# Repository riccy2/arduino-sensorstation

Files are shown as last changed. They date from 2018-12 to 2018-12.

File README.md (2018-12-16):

# Arduino Sensorstation

## Zusammenfassung
Hochpräzise Vermessungsarbeiten erfordern oft eine genaue Kenntnis des Mediums Luft. Temperatur, Luftdruck und relative Luftfeuchte beeinflussen die benötige Laufzeit von Wellen, die für Streckenmessungen genutzt werden. Das Ziel dieser Arbeit ist, eine kostengünstige Lösung zu entwickeln, die es ermöglicht, flächendeckend Korrekturwerte für hochpräzise Messungen zu liefern. Dazu wird mithilfe der Hard- und Softwareplattform Arduino ein Prototyp entwickelt, welcher Temperatur, Luftdruck und Luftfeuchte messen und an eine zentrale Stelle via WLAN weiterleiten kann. Dazu wurden verschiedene Sensoren hinsichtlich ihrer Genauigkeit untersucht und weitere für eine ausfallsichere Datenerfassung benötigte Komponenten ausgewählt. Ein Programm für die Steuerung einer Messstation sowie für den zentralen Server wurde entwickelt. Das Ergebnis ist Sensornetzwerk, dessen Knoten einen Materialpreis von etwas über 10 € aufweisen und trotzdem genaue Messwerte erfassen.

## Abstract
High-precision surveying work often requires precise knowledge of the medium air. Temperature, air pressure and relative humidity influence the required running time of waves used for distance measurements. The aim of this work is to develop a cost-effective solution that allows to provide area-wide correction values for high-precision measurements. A prototype will be developed using the Arduino hardware and software platform, which can measure temperature, air pressure and humidity and transmit them to a central location via WLAN. For this purpose, various sensors were examined with regard to their accuracy and further components required for fail-safe data acquisition were selected. A program to control a sensor station as well as one for the central server was developed. The result is a sensor network, whose nodes have a material price of just over 10 € and still record accurate measured values.

## Inhalt dieses Repository

### Bachelor Thesis
Die pdf-Datei **thesis.pdf** enthält die Bachelor-Thesis **Low-cost Umweltmonitoring mit Arduino in Geosensornetzwerken** von Riccardo Oppermann. Betreut wurde diese Arbeit an der HafenCity Universität Hamburg von den Herren Prof. Dr.-Ing. Harald Sternberg und Dipl.-Umweltwiss. Dipl.-Ing. Günter Eppinger.

### Arduino Code
Dieser Ordner enthält den Quellcode für eine Sensorstation. **SensorStation.ino** ist das Main Sketch File.

### Layout
Dieser Ordner enthält ein Bild des mit fritzing erstellten Layouts sowie Schaltplans einer Sensorstaton. Ebenfalls finden sich dort Bilder einer fertigen Sensorstation auf einem PCB.

### PCB-Design
In diesem Ordner ist das entworfene Board in Form einer Eagle-CAD-Boarddatei sowie einer fertigen Gerber-Datei.

### Server-Code
In diesem Ordner befindet sich der Code des PHP-Scripts zum Speichern der Messwerte (**send_data.php**) sowie eines zum Abrufen von Daten (**get_data.php**). Dieses Script zum Abrufen wird von der Testapplikation **index.php** genutzt. Die Testaplikation kann die Daten verschiedener Stationen in einer mit AmCharts erstellten Grafik darstellen.
Die Datei **weather.sql** enthält die Struktur der MySQL-Datenbank.

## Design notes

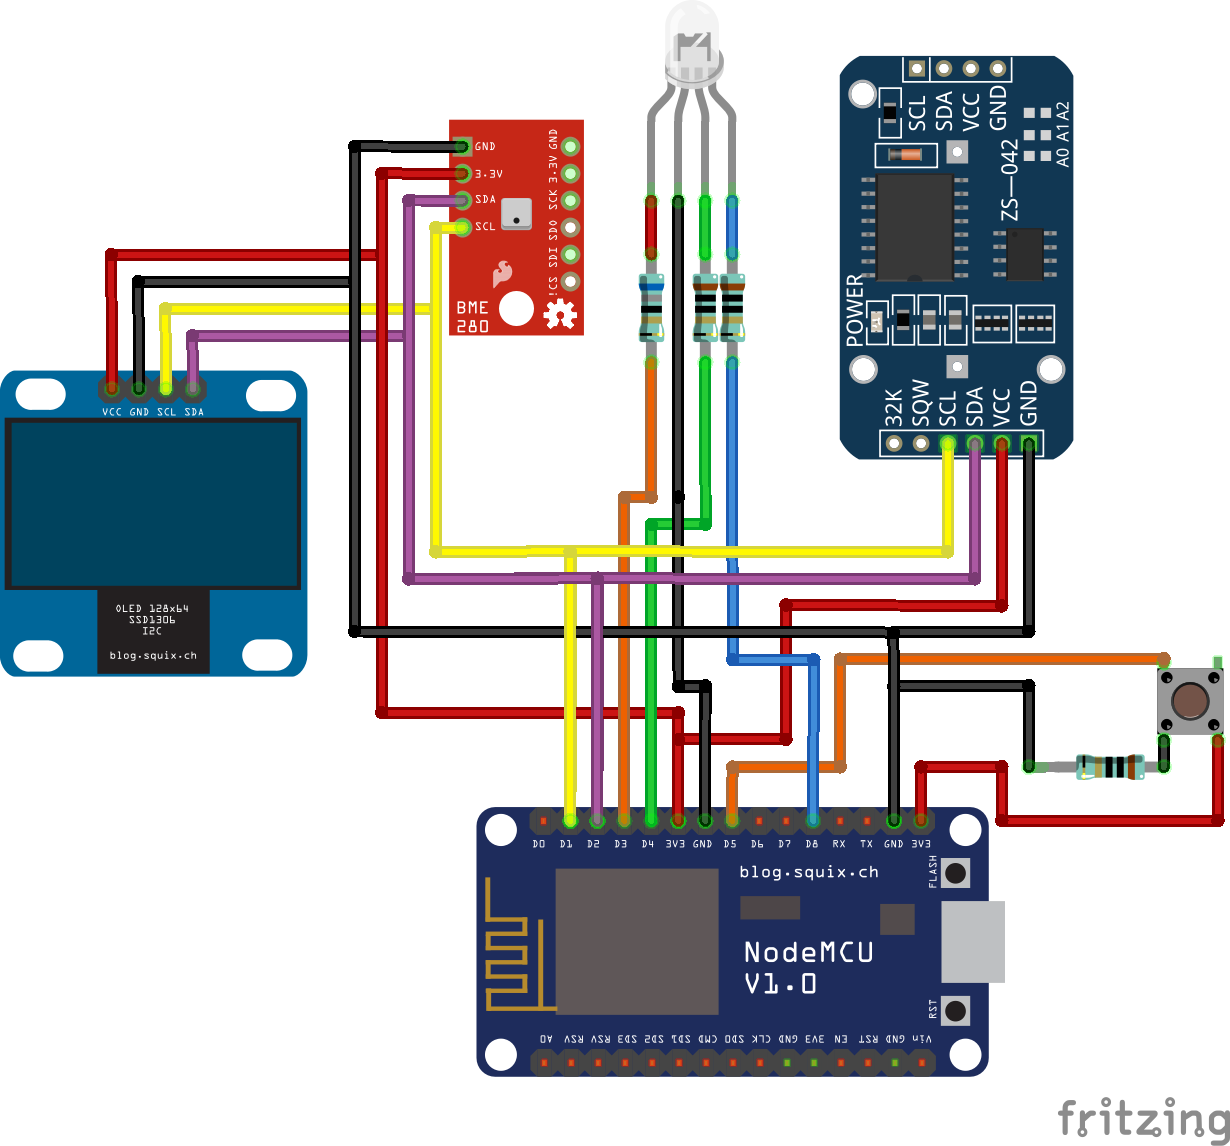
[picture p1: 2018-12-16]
Layout/layout_Steckplatine.png

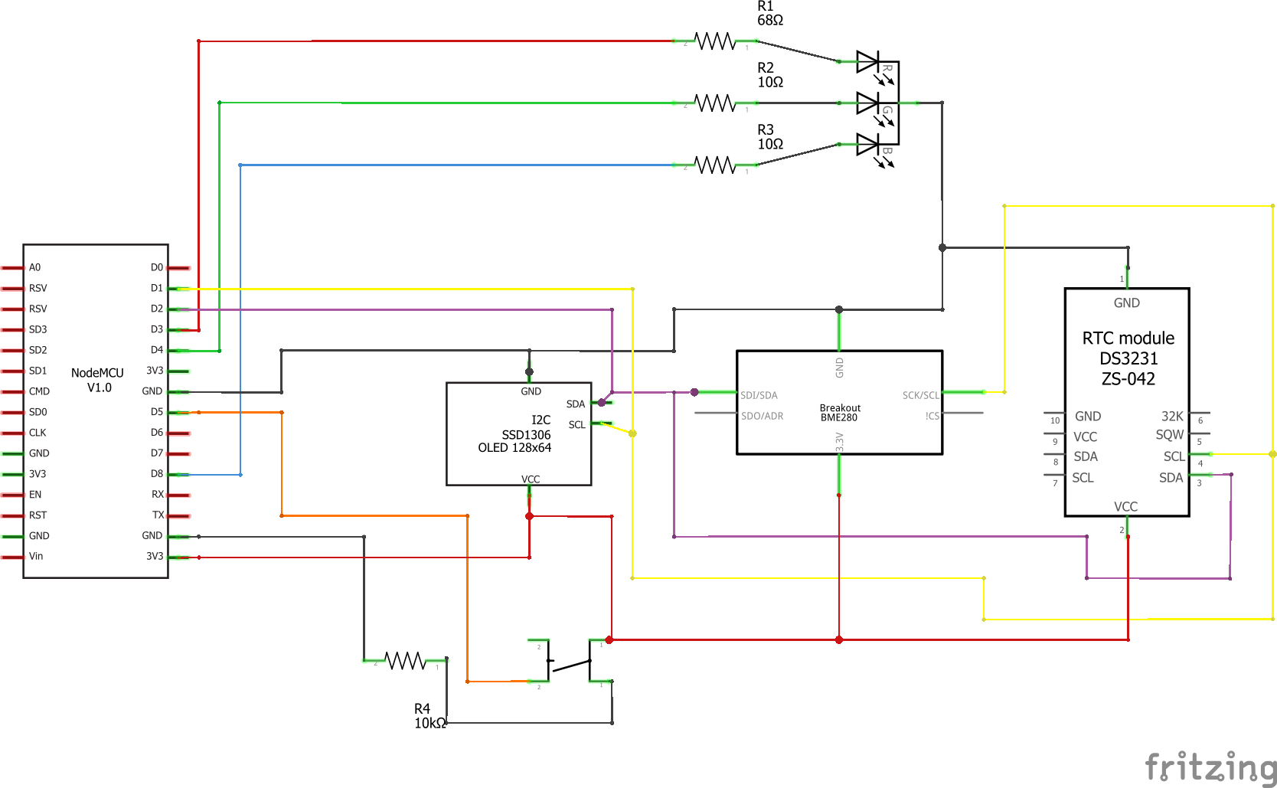
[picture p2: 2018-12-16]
Layout/layout_Schaltplan.png

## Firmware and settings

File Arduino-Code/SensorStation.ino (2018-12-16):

/*
   ** SensorStation **
   Programm zur Erfassung und Übermittlung von Wetterdaten
   Autor: Riccardo Oppermann
   Datum: November + Dezember 2018
   Verwendete Komponenten: NodeMCU v2 Amica, Bosch BME280 Modul, DS3231 RTC Modul, 1.3" I2C OLED Display, 

   NodeMCU I2C
   SDA -> D2 (GPIO 4) Standard
   SCL -> D1 (GPIO 5) Standard
   Falls andere Pins genutzt werden sollen, diese festlegen mit Wire.begin(SDApin,SCLpin);

   LED
   Rot  -> D3 (GPIO 0)
   Grün -> D4 (GPIO 2)
   Blau -> D8 (GPIO 15)

   Button
   Signal -> D5 (GPIO 14)
   

*/

#include <FS.h>                   //muss an erster Stelle stehen

#include <Adafruit_Sensor.h>      //https://github.com/adafruit/Adafruit_Sensor
#include <Adafruit_BME280.h>      //https://github.com/adafruit/Adafruit_BME280_Library change I2C-Adress to 0x76
#include <RTClib.h>               //https://github.com/adafruit/RTClib
#include <U8g2lib.h>              //https://github.com/olikraus/u8g2
#include <U8x8lib.h>              //https://github.com/olikraus/u8g2
#include <Wire.h>                 //https://www.arduino.cc/en/Reference/Wire
#include <SPI.h>                  //https://www.arduino.cc/en/Reference/SPI
#include <ESP8266WiFi.h>          //https://github.com/esp8266/Arduino
#include <DNSServer.h>            //https://github.com/esp8266/Arduino
#include <ESP8266WebServer.h>     //https://github.com/esp8266/Arduino
#include <WiFiClientSecure.h>     //https://github.com/esp8266/Arduino
#include <WiFiManager.h>          //https://github.com/tzapu/WiFiManager
#include <ArduinoJson.h>          //https://github.com/bblanchon/ArduinoJson Version 5.X.X


WiFiClientSecure client;
WiFiManager wifiManager;
File logDatei;
String line;
Adafruit_BME280 bme280;
RTC_DS3231 rtc;
U8G2_SH1106_128X64_NONAME_F_HW_I2C u8g2(U8G2_R0, /* reset=*/ U8X8_PIN_NONE);


int SDAPIN = 4; // D2
int SCLPIN = 5; // D1
int REDPIN = 0; // D3
int GREENPIN = 2; // D4
int BLUEPIN = 15; // D8
int buttonPin = 14; // D5



// Einstellungen
bool buttonConnected = true;  // auf false setzen, falls kein Button angeschlossen wurde
const char* url = "www.weatherweb.de"; // Serveradresse der API, erwartet folgende Dateistruktur: "/api/send_data.php"



// Globale Statusvariablen, werden vom Programm gesetzt
float bme280Temp;
float bme280Pres;
float bme280Humi;
const char* stationname;
String message = "";
char web_token[34] = "";
int intervall = 1;
bool showWifiPortal = true;
bool shouldSaveConfig = false;
bool spaceAvailable = false;
bool displayConnected = false;
bool rtcConnected = false;
bool bme280Connected = false;
bool httpFail = false;
unsigned long lastProcess = 0;
unsigned long lastDisplayRefresh = 0;
bool LEDBLINK = false;
int REDCOLOR = 0;
int GREENCOLOR = 0;
int BLUECOLOR = 0;




void setColor(int red, int green, int blue, bool blinkMode = false);

// wird aufgerufen, wenn die Wifi-Konfiguration gespeichert werden soll
void saveConfigCallback () {
  Serial.println("Konfiguration speichern");
  shouldSaveConfig = true;
}


void setup() {
  pinMode(REDPIN, OUTPUT);
  pinMode(GREENPIN, OUTPUT);
  pinMode(BLUEPIN, OUTPUT);
  pinMode(buttonPin, INPUT);
  
  Serial.begin(9600);
  Wire.begin(SDAPIN, SCLPIN);
  delay(1000);

  Wire.beginTransmission(104); // entspricht 0x68 (DS3231 Adresse)
  byte errorRTC = Wire.endTransmission();
  if (errorRTC == 0) {
    Serial.println("I2C RTC gefunden");
    rtcConnected = true;
  }
  if (rtcConnected) {
    rtc.begin();
    if (rtc.lostPower()) {
      Serial.println("RTC Zeit wird gesetzt");
      // RTC Zeit auf den Zeitpunkt der Kompilierung setzen
      rtc.adjust(DateTime(F(__DATE__), F(__TIME__)));
    }
  }

  Wire.beginTransmission(60); // entspricht 0x3C (Display Adresse)
  byte errorDisplay = Wire.endTransmission();
  if (errorDisplay == 0) {
    Serial.println("I2C Display gefunden");
    displayConnected = true;
  }
  if (displayConnected) {
    u8g2.begin();
    u8g2.enableUTF8Print();
  }

  infoDisplay("", "Bitte warten", "Starte Station...", "");
  delay(500);

  Wire.beginTransmission(118); // entspricht 0x76 (BME280 Adresse)
  byte errorBME280 = Wire.endTransmission();
  if (errorRTC == 0) {
    Serial.println("I2C BME280 gefunden");
    bme280Connected = true;
  }
  if (bme280Connected) {
    bme280.begin();
  } else {
    Serial.println("Konnte keinen BME280 Sensor finden, Programm wird abgebrochen.");
    infoDisplay("", "Fehler", "Kein BME280 gefunden", "");
    while (1) {
      analogWrite(REDPIN, 255);
    };
  }

  

  //clean FS, for testing
  //SPIFFS.format();

  //read configuration from FS json
  Serial.println("mounting FS...");

  if (SPIFFS.begin()) {
    Serial.println("mounted file system");
    if (SPIFFS.exists("/config.json")) {
      //file exists, reading and loading
      Serial.println("reading config file");
      File configFile = SPIFFS.open("/config.json", "r");
      if (configFile) {
        Serial.println("opened config file");
        size_t size = configFile.size();
        // Allocate a buffer to store contents of the file.
        std::unique_ptr<char[]> buf(new char[size]);

        configFile.readBytes(buf.get(), size);
        DynamicJsonBuffer jsonBuffer;
        JsonObject& json = jsonBuffer.parseObject(buf.get());
        json.printTo(Serial);
        if (json.success()) {
          Serial.println("\nparsed json");

          strcpy(web_token, json["web_token"]);
          // already configured
          showWifiPortal = false;

        } else {
          Serial.println("failed to load json config");
        }
        configFile.close();
      }
    }
  } else {
    Serial.println("failed to mount FS");
  }
  //end read






  if (showWifiPortal) {
    infoDisplay("", "Wlan einrichten", "", "");


    // The extra parameters to be configured (can be either global or just in the setup)
    // After connecting, parameter.getValue() will get you the configured value
    // id/name placeholder/prompt default length
    WiFiManagerParameter par_web_token("token", "Token", web_token, 32);
  
    //set config save notify callback
    wifiManager.setSaveConfigCallback(saveConfigCallback);
  
    //add all your parameters here
    wifiManager.addParameter(&par_web_token);
  
    //reset settings - for testing
    // wifiManager.resetSettings();

    if (!wifiManager.startConfigPortal()) {
      Serial.println("failed to connect and hit timeout");
      delay(3000);
      //reset and try again, or maybe put it to deep sleep
      ESP.reset();
      delay(5000);
    }

    //if you get here you have connected to the WiFi
    Serial.println("connected to wifi");
    infoDisplay("verbunden mit", String(WiFi.SSID()), "", WiFi.localIP().toString());
    delay(1000);
  
    //read updated parameters
    strcpy(web_token, par_web_token.getValue());
    
  } else{
    wifiManager.autoConnect();
  }

  

  //fetches ssid and pass and tries to connect
  //if it does not connect it starts an access point
  //and goes into a blocking loop awaiting configuration
//  if (!wifiManager.autoConnect()) {
//    Serial.println("failed to connect and hit timeout");
//    delay(3000);
//    //reset and try again, or maybe put it to deep sleep
//    ESP.reset();
//    delay(5000);
//  }



  //save the custom parameters to FS
  if (shouldSaveConfig) {
    Serial.println("saving config");
    DynamicJsonBuffer jsonBuffer;
    JsonObject& json = jsonBuffer.createObject();
    json["web_token"] = web_token;

    File configFile = SPIFFS.open("/config.json", "w");
    if (!configFile) {
      Serial.println("failed to open config file for writing");
    }

    json.printTo(Serial);
    json.printTo(configFile);
    configFile.close();
    //end save
  }

  Serial.println("local ip");
  Serial.println(WiFi.localIP());

}

void loop() {

  if (buttonConnected) {
    int buttonState = 0;
    buttonState = digitalRead(buttonPin);
    if (buttonState == HIGH) {
      Serial.println("button pressed");
      delay(200);
      SPIFFS.remove("/config.json");
      delay(200);
      wifiManager.resetSettings();
      delay(1000);
      ESP.restart();
    }
  }
  
  ledBlinker();
  
  if (processStarter()) {

    httpFail = false;

    spaceAvailable = checkSpace();

    bme280Temp = bme280.readTemperature();
    bme280Pres = bme280.readPressure() / 100;
    bme280Humi = bme280.readHumidity();

    String postStr = "action=update";
    postStr += "&temp=" + String(bme280Temp);
    postStr += "&pres=" + String(bme280Pres);
    postStr += "&humi=" + String(bme280Humi);
    postStr += "&token=" + String(web_token);
    String responseBody = sendRequest(postStr);


    StaticJsonBuffer<200> jsonBuffer;
    JsonObject& body = jsonBuffer.parseObject(responseBody);

    const char* requestStatus;
    if (body.containsKey("status")) {            // Erhalte Request-Status vom Server
      requestStatus = body["status"];
    }

    if (body.containsKey("stationname")) {       // Erhalte Stationsname vom Server
      stationname = body["stationname"];
    }

    if (body.containsKey("intervall")) {          // Erhalte Intervall in Minuten vom Server
      intervall = body["intervall"];
    }

    unsigned int timestamp;
    if (body.containsKey("timestamp")) {        // Erhalte Unix-Timestamp vom Server, so kann die RTC aktuell gehalten werden, solange Internet da ist.
      timestamp = body["timestamp"];     
      if (rtcConnected) {
        rtc.adjust(DateTime(timestamp));
      }
      timestamp = timestamp + 7200;   // Wegen Zeitzone + 2 Stunden - erst nachdem RTC gestellt wurde, da unixzeit zeitzonenunabhängig ist
    }

    

    if (strcmp(requestStatus, "success") == 0) {
      Serial.println("Real Time Request successful");
      String minutes, hours;
      if (DateTime(timestamp).minute() < 10) {
        minutes = "0" + String(DateTime(timestamp).minute());
      } else {
        minutes = String(DateTime(timestamp).minute());
      }
      if (DateTime(timestamp).hour() < 10) {
        hours = "0" + String(DateTime(timestamp).hour());
      } else {
        hours = String(DateTime(timestamp).hour());
      }
      message = "zuletzt " + hours + ':' + minutes;
      setColor(0, 255, 0);
    } else if (strcmp(requestStatus, "error_mysql") == 0) {
      setColor(0, 0, 255, true);
      Serial.println("error_mysql");
      message = "SQL Fehler";
      httpFail = true;
    } else if (strcmp(requestStatus, "error_token") == 0) {
      Serial.println("error_token");
      wifiManager.resetSettings();
      delay(1000);
      ESP.restart();
    } else if (strcmp(requestStatus, "error_client") == 0) {
      Serial.println("error_client");
      message = "Wifi Fehler";
      setColor(255, 140, 0, true);
      httpFail = true;
    } else {
      // unbekannter Fehler
      Serial.println("Real Time Request failed");
      message = "unbekannter Fehler"; 
      httpFail = true;
    }

    refreshDisplay(String(stationname), bme280Temp, bme280Pres, bme280Humi, message);

    if (httpFail) { 
      // HTTP-Request konnte nicht abgesetzt werden
      writeLog();
    } else {  
      // voheriger Request konnte abgesetzt werden, Connection ist also vorhanden -> Cache checken und abarbeiten
      sendLog();
    }

    Serial.println("---------------------------------------");
  } // end Process

}


String getTimeString(DateTime now) {
  String timeString;

  timeString = String(now.year()) + '-' + String(now.month()) + '-' + String(now.day());
  timeString = timeString + ' ';
  timeString = timeString + String(now.hour()) + ':' + String(now.minute()) + ':' + String(now.second());
  return timeString;
}

void setColor(int red, int green, int blue, bool blinkMode) {
  REDCOLOR = red;
  GREENCOLOR = green;
  BLUECOLOR = blue;
  LEDBLINK = blinkMode;
}

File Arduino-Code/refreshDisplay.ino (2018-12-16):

  
  void refreshDisplay(String stationname, float temp, float pres, float humid, String message) {
    if (displayConnected) {
      String cTemp = String(temp) + " C";
      String cPres = String(pres) + " hPa";
      String cHumi = String(humid) + " %";
      
      u8g2.clearBuffer();
      u8g2.setFont(u8g2_font_7x14B_tf);
      u8g2.drawStr(0,12,stationname.c_str()); 
      u8g2.setFont(u8g2_font_helvR08_tf);
      u8g2.drawStr(0,26,"Temperatur:");
      u8g2.drawStr(64,26,cTemp.c_str());
      u8g2.drawStr(0,38,"Luftdruck:");
      u8g2.drawStr(64,38,cPres.c_str());
      u8g2.drawStr(0,50,"Luftfeuchte:");
      u8g2.drawStr(64,50,cHumi.c_str());
      u8g2.drawStr(0,62,message.c_str());
      u8g2.sendBuffer();
    }
  }
